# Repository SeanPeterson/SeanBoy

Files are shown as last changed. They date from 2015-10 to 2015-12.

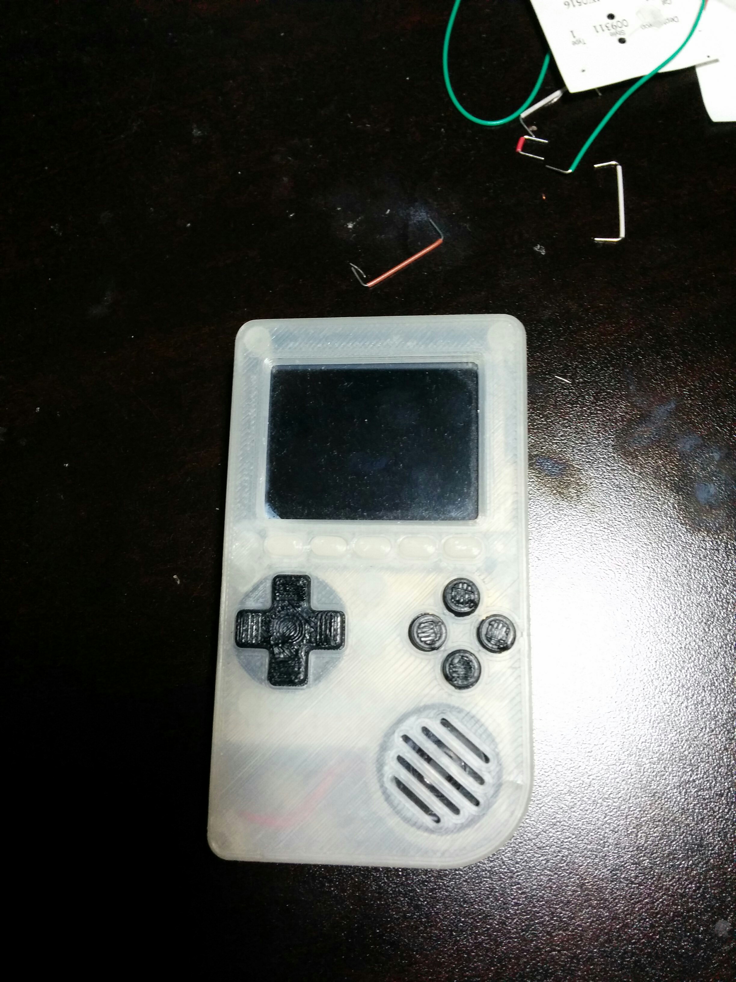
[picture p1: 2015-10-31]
Img/IMG_20151020_160937.jpg

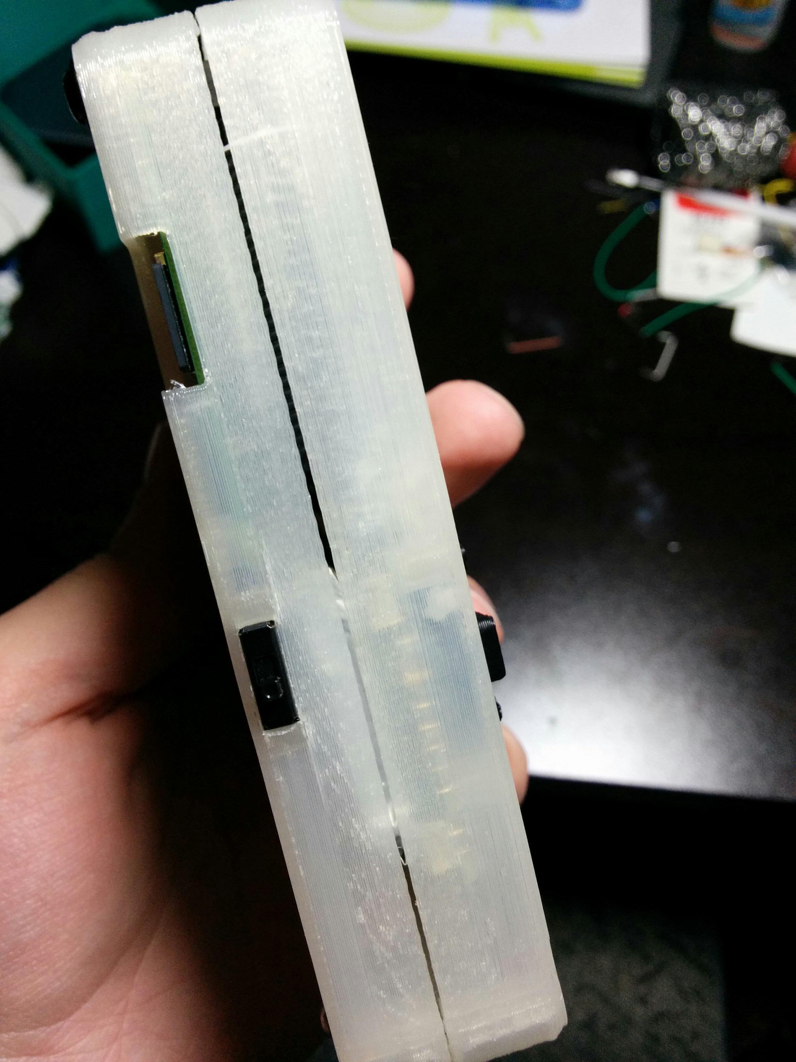
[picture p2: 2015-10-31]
Img/IMG_20151020_160956.jpg

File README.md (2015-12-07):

# CS207 Final Project
# A fork of the Pocket PiGrrl
Sean Peterson - University of Regina
*Fall 2015 *

#Video of Assembly
https://youtu.be/0lDeOTESRT8

# Overview
The goal of this project is to improve upon Adafruit’s Pocket Pigrrl design in various ways. Ultimately the plan is to roughly keep the same dimensions while also adding a Raspberry Pi 2, an audio jack, and improving durability by ensuring that everything fits snuggly. From the software standpoint the project plans on providing a method in which the save states of games can not only be backup up to a cloud service, but that will effectively sync saved games between devices that are linked to the same cloud service.

# Goals
1. The first milestone will be to build the original Pocket PiGrrl design. This will achieve a few things. Firstly, it will provide a good idea of the amount of space there is to work with. Secondly, it will help to understand the logic behind their design

2. The second milestone will be the inclusion of an audio jack. The PiGrrl currently only supports sound through a speaker which is inconvenient when there are other people in the same room as you. Doing this may require wiring a switch, to switch between the speaker and headphones.

3. The third milestone will be to use a different button design. This is because the PiGrrl uses NinjaFlex filament to print their buttons. Unfortunately this is a material not supported by the author’s 3D printer. Instead, the plan will be to take apart an original, or knock off, snes controller and use its buttons instead. This will both eliminate the noise  

4. The fourth deliverability will be to backup save states to a cloud service, and also have the saves sync between different Raspberry Pi’s that may be connected to a single account. 

5. The fifth deliverability will be to use a Raspberry Pi2 instead, while keeping the size roughly the same. This would be a welcome improvement as it would greatly improve the systems emulation capabilities. As well, this may also mean adding an improved power supply to the console. 

<h1>Build Instructions (Currently for goal 1 to goal 3)</h1>

-download CAD files from CAD folder (currently for goal 3), and print (Goal one/original design by AdaFruit found: https://www.thingiverse.com/thing:807591) <br>
-Pocket PiGrrl build instructions can be found here: https://learn.adafruit.com/pocket-pigrrl/overview <br>
(Go to goal 2 section to see how to install audio jack. <br>
-Download latest ISO image from Software folder. Install on SD card for Raspberry Pi (detailed installation instructions <br>
for different operatings systems can be found in the info file inside software directory). <br>
-Button mappings for Adafruit's PiTFT screen can be found here: https://learn.adafruit.com/pocket-pigrrl/software-1 <br>
-See goal 3 for assembly instructions https://github.com/SeanPeterson/SeanBoy/blob/master/Goal-3/goal3.pdf
# Known Issues/Planned fixes
-(FIXED - SEE GOAL 1) Currently the sound has major interference.. This problem seems to be a known issue as reported on the AdaFruit forums that is either resulting from the AdaFruit's amp, or the pi itself. <https://forums.adafruit.com/viewtopic.php?f=50&t=79200> <br>
-(FIXED IN GOAL 3) There's a gap between the top and bottom of the gameboy case. May need to extend sides and sand it down.<br>
-(FIXED IN GOAL 3) Magnet not doing a good job of keeping the case close, another screw in bottom right corner would work better. <br>

#Materials
-Raspberry Pi A+ (Exluding goal 5): <br>
-2.4 Pitft screen: https://adafruit.com/products/2455<br>
-Powerboost 1000C: https://adafruit.com/products/2465<br>
-SparkFun mono amp breakout: https://www.sparkfun.com/products/11044<br>
-Battery: https://www.adafruit.com/products/2011<br>
-Solder breadboard: http://www.amazon.ca/s/ref=nb_sb_noss_2?url=search-alias%3Daps&field-keywords=solder+breadboard<br>
-26 pin ribbon cable: https://www.adafruit.com/product/862<br>
-Tactile buttons: https://www.adafruit.com/product/1489<br>
-Mini speaker: https://www.adafruit.com/product/1890<br>
-Slide switch <br>
-Knockoff nes controller: http://www.amazon.ca/RetroLink-NES-Classic-USB-Controller/dp/B009DG2WZS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<br>
-Audio jack: http://www.canadarobotix.com/cables-wires/audio-jack-3-5-mm<br>
-6 pin switch: Scavange from old electronics<br>

# Project
Code, and diagrams can be found here: https://github.com/SeanPeterson/SeanBoy

Note: Work in progress, code/diagrams are added as worked on
This is free and unencumbered software released into the public domain. <br>

#Contact
Email: seanpeterson.997@gmail.com <br>
For questions about the project the best place to ask is on this projects Thingverse page <br>
Link coming soon ...

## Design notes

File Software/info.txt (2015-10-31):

<h1>Install info</h1>

ISO from Adafruit contains operating systems (RetroPie) complete with EmulationStation (emulators) and <br>
Adafruit's software for a ptft screen. <br>

Code and inputs for buttons on Ptft screen 

<h1>Installing image onto SD card for Raspberry PI</h1>

<h2>Windows</h2>
1) Format drive to FAT32 <br>
Note: Since windows can't see the OS partition, a 3rd party software solution is required for this. <br>
I recommend the free program MiniTool Partition Wizard: http://www.partitionwizard.com/download.html <br>

2) Install image to SD card (Again need a 3rd party software solution) <br>
-For this I recommend the free software tool Win32 Disk Manager:http://sourceforge.net/projects/win32diskimager/

<h2>Linux</h2>
-Instructions can be found here: <br>
https://www.raspberrypi.org/documentation/installation/installing-images/linux.md

<h2>Mac OS</h2>
-Instructions can be found here: <br>
https://www.raspberrypi.org/documentation/installation/installing-images/mac.md

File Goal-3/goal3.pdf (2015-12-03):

P a g e | 1

Goal 3 Outcome

1. Materials: Page 2
2. Build Instructions: Pages 2 – 9

-Pages 2 – 3 AdaFruit Tutorials

-Pages 4-6: Buttons

- Pages 7-9: Case
3. Result Pictures: Pages 10-11
4. Problems: Page 11
5. Lessons Learned: Pages 10-11

Materials

-Retrolink Nes controller: Can be found on Amazon: http://www.amazon.ca/RetroLink-NES-Classic-USB-Controller/dp/B009DG2WZS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 (http://www.amazon.ca/RetroLink-NES-Classic-USB-Controller/dp/B009DG2WZS)

-Solder breadboard

-Lenline brush to scrape the traces.

Build Instructions

1) Install power switch: https://learn.adafruit.com/pocket-pigrrl/switch
2) Install power boost 1000: https://learn.adafruit.com/pocket-pigrrl/powerboost-1000c
3) Not using the PAM8302, instead using Sparkfun Mono amp found Here: https://www.sparkfun.com/products/11044

Setup is still the exact same as AdaFruit’s: https://learn.adafruit.com/pocket-pigrrl/pam8302

5V from powerboost to PWR + on amp

GND from powerboost to PWR – on amp

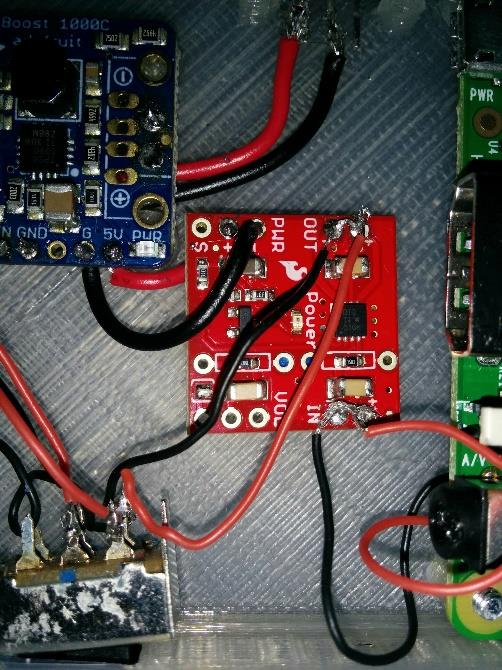
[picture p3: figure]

4) Pi audio: https://learn.adafruit.com/pocket-pigrrl/pi-audio
5) Speaker: https://learn.adafruit.com/pocket-pigrrl/speaker
6) Screen: https://learn.adafruit.com/pocket-pigrrl/2-dot-4-pitft

Buttons taken from a retrolink nes controller:

7) Pi Cable: https://learn.adafruit.com/pocket-pigrrl/pi-cable
8) Mount display: https://learn.adafruit.com/pocket-pigrrl/mount-display
9) Installing buttons:

-Cut out breadboard that fits snuggly into case aprox(63mm wide, 53mm long)

Take Apart a RetroLink Nes controller and remove PCB board.

Make cuts so that they fit on proto board and line up with the button cut outs on the case

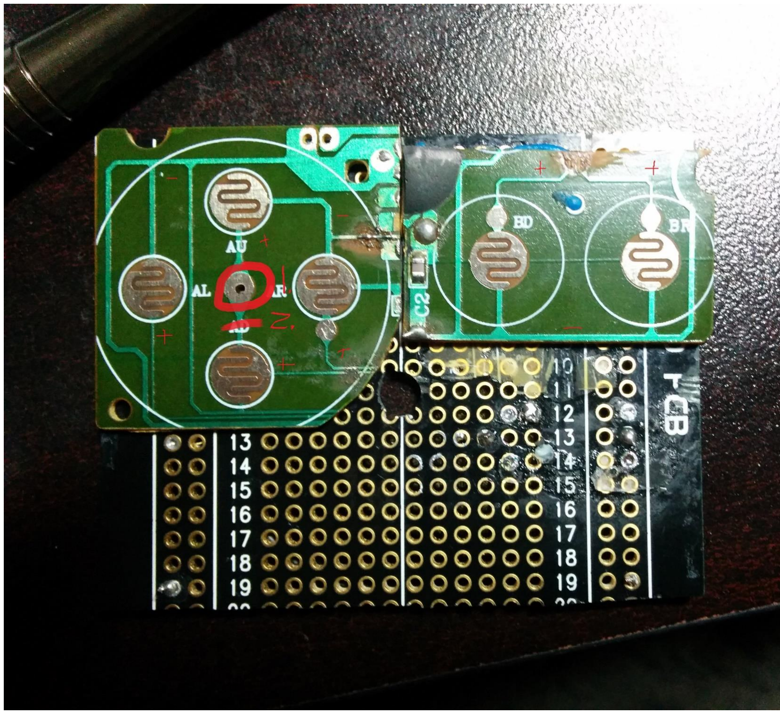
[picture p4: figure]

1. Needed drill press to make a hole here so that I could get the up wire to the button
2. Trace cut

+ are the traces that I wired the buttons to

- Are the ground traces.

Make sure that each button has a ground (can be shared), and a positive (where the button will be wired). Expose the trace by scraping it with a Lenline brush, and tin the location you desire to prepare for the solder. This may require using a drill press as seen in picture above to make a hole in a specific location. As well, you may need to perform trace cuts.

-Also ensure that the wires are not underneath the elastomer gaskets as that will effect the feel and functionality. Instead make sure buttons are wired at enough of a distance away from the elastomer gaskets to allow for some mistakes to be made (if a trace falls off).

-Now solder the button wires from the screen to the breadboard. Buttons can of course go to any location on your breadboard that is convenient but here is my set up in the picture below.

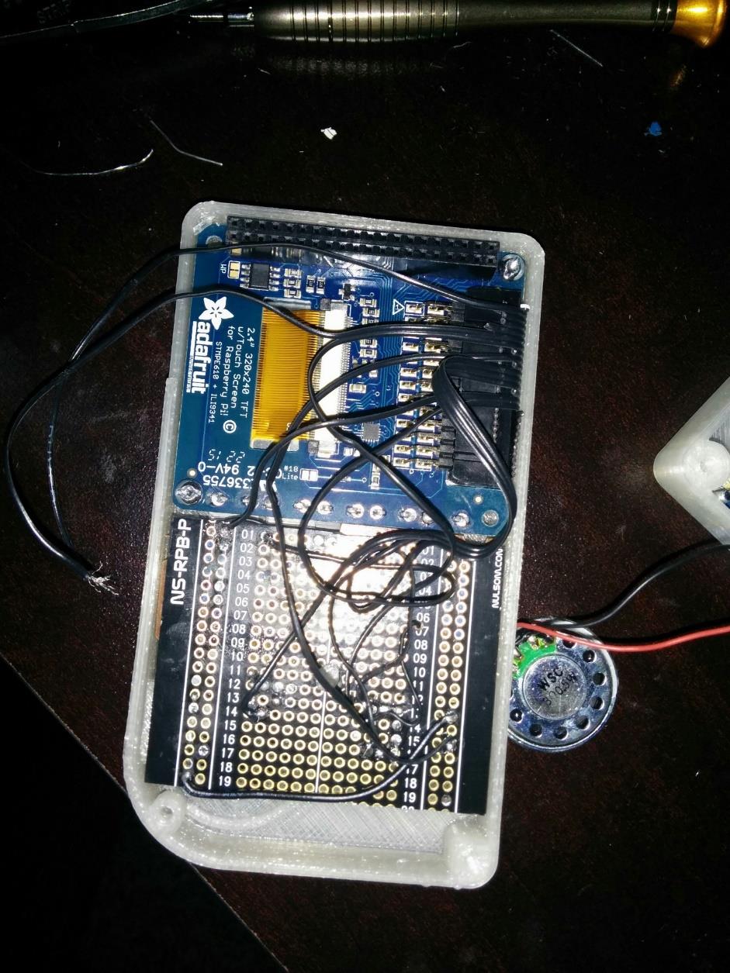
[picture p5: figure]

(Wired the buttons to the back of the breadboard, then from the breadboard to the buttons)

The wire numbers are the same as AdaFruit’s tutorial found here: https://learn.adafruit.com/pocket-pigrrl/buttons

Note rows are split in half (ex say row 16 can have wires on both sides)

#9 Ground → Goes to ground of breadboard (I’ve connected both grounds together as seen above)

#7 Left → row 16 (Dpad side)

#11 Right → Row 15

#12 Up → Row 14

#13 Down → Row 13

#15 A → Positive Row (on the buttons side)

#16 B → Row 1

-Now wire from the BreadBoard locations to the correct buttons.

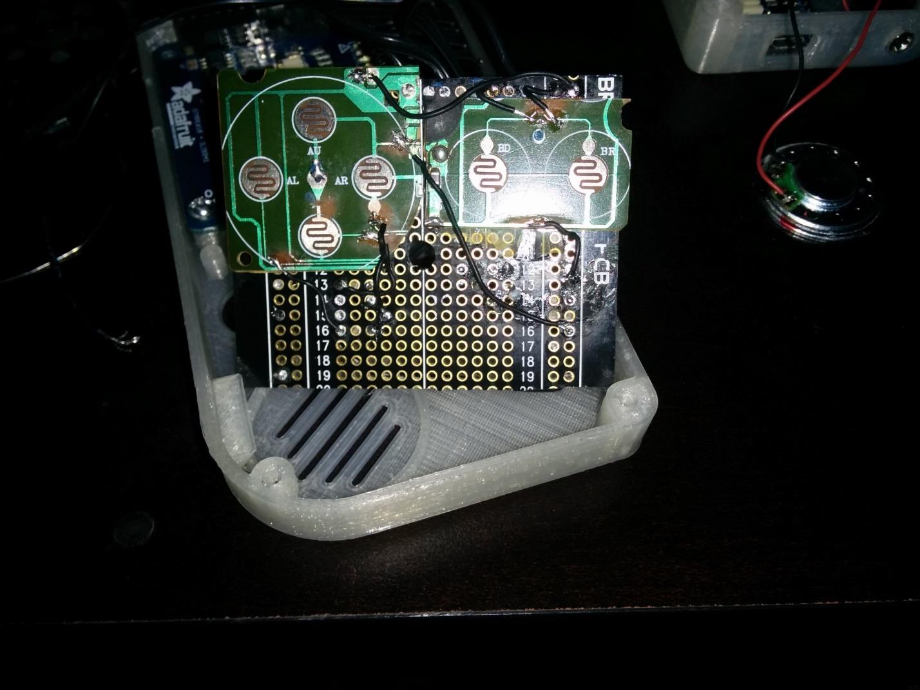
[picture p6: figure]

-Place the buttons in the correct slots. Line up the elastomer gaskets on top of the buttons (a small amount of sticky tack may help but too much will hinder it).

-Line the breadboard up with the screw hole standoff (should also be resting on the four corner standoffs) and screw into place with a SIZE screw.

-Assemble the case, same as Adafruit instructions excep that there is a screw in bottom right corner instead of a magnet.

https://learn.adafruit.com/pocket-pigrrl/assembly

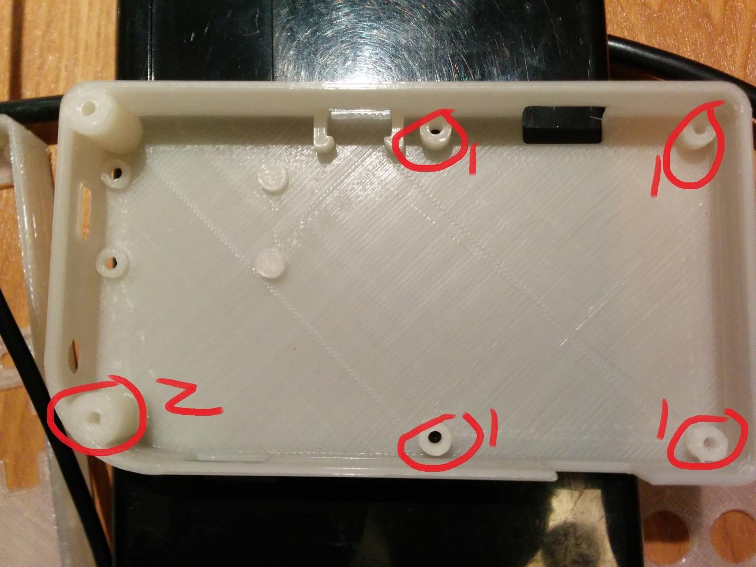
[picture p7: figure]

(Modifications made to the bottom of the case)

1: Raised screw standoffs for Raspberry Pi by 2mm

2: Added screw hole for bottom left side of case (will screw into the top case to replace the magnet in Adafruit’s design).

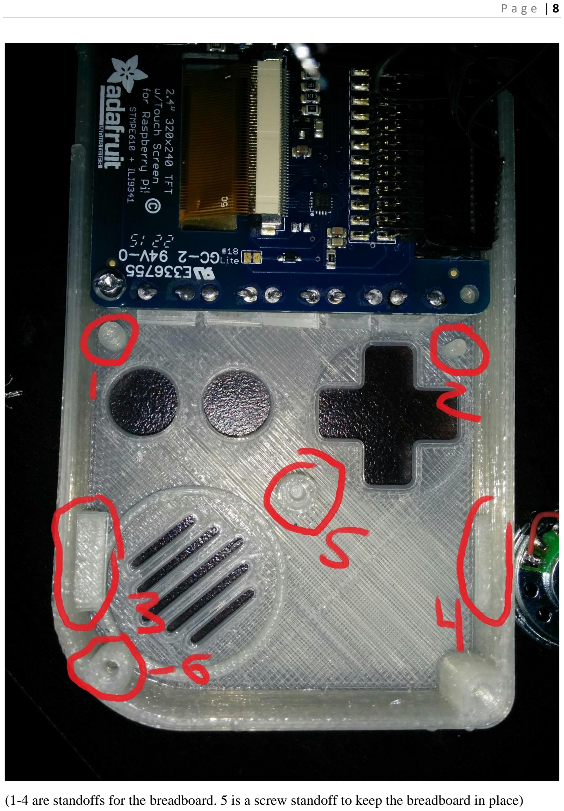
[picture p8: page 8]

(1-4 are standoffs for the breadboard. 5 is a screw standoff to keep the breadboard in place)

1-4 are to prevent the breadboard from tilting in any direction when a buttons are pressed. 5 is to prevent the bread board from moving horizontally out of place. (The case will be packed enough that the breadboard will not be able to move horizontally out of place.

6. Screw hole that replaces the magnet that is in Adafruit’s design

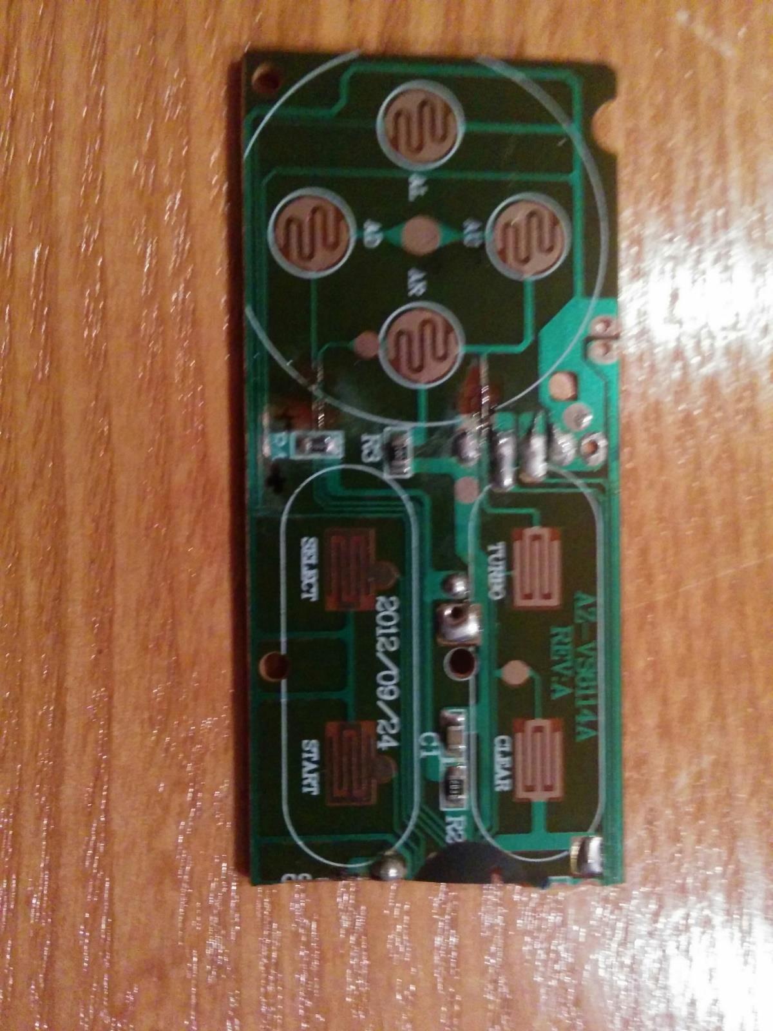
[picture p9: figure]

(DPAD PCB before the cut)

Result Pictures

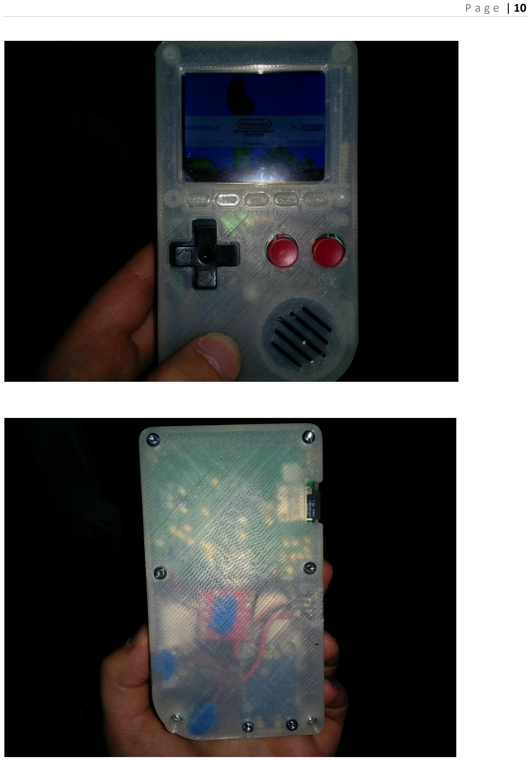
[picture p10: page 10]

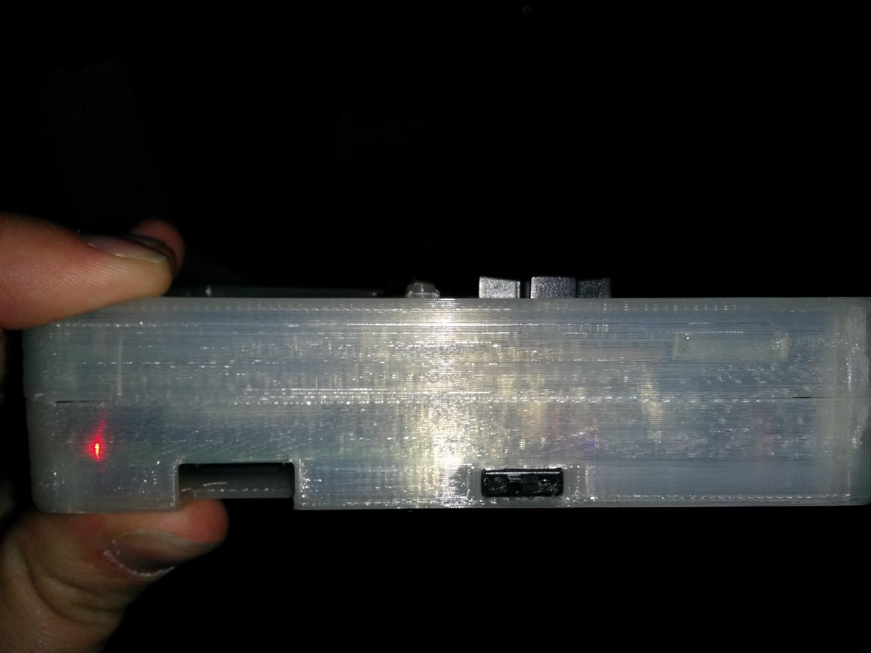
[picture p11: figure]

Problems

Problem: The buttons could still use some improvement in resistance to presses.

Solution: Minor tweaking with space (lower the standoffs a bit more)

Problem: GPIO pins on pi could fit a bit better into the screen

Solution: Tweak the height of the Raspberry Pi’s standoffs (probably just a mm or two)

Lessons Learned

1. This goal ended up being a lot more challenging than initially expected. A general principle I’ve learned is that when scavenging buttons from a controller it is a good idea to try and implement the same (or similar) design as was being used in the controller you took the buttons from.

2. Don’t have any wires soldered below the elastomer gaskets as they will get in the way of button presses and make the buttons unreliable and uncomfortable.
3. Leave lots of room to solder the wires to the traces as pulling a wire too hard will often rip a piece of the trace off of the PCB.
4. Spacing is extremely important to the feel and functionality of the buttons (resulting in a lot of prototyping in the CAD design).

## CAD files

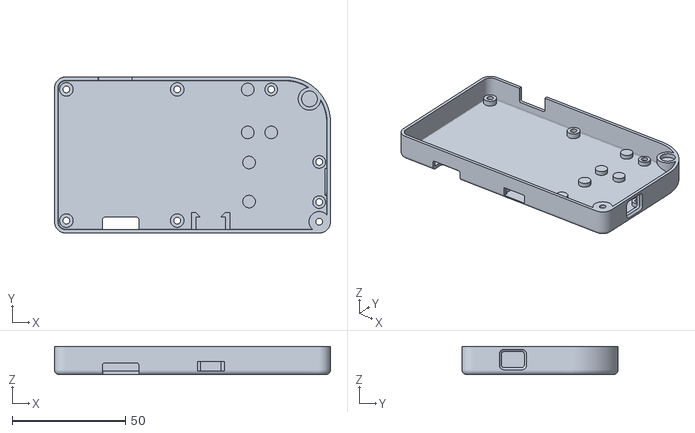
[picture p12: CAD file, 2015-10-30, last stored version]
CAD/pgp-4-bot.stl
122.0 x 69.0 x 12.4

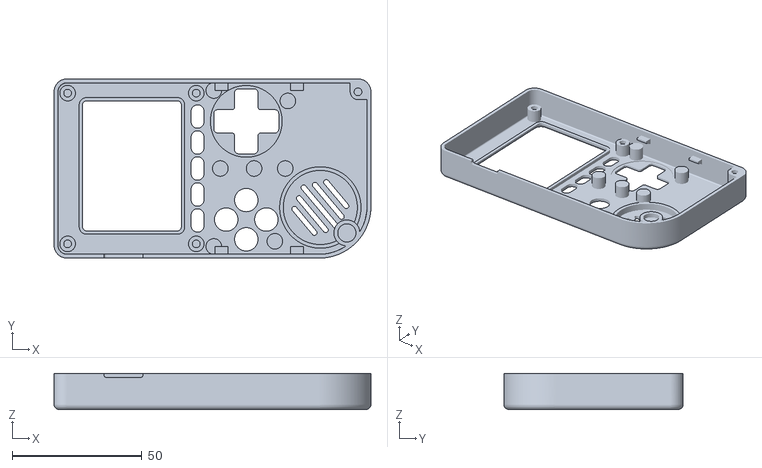
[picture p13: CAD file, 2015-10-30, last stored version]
CAD/pgp-4-top.stl
122.0 x 69.0 x 13.9

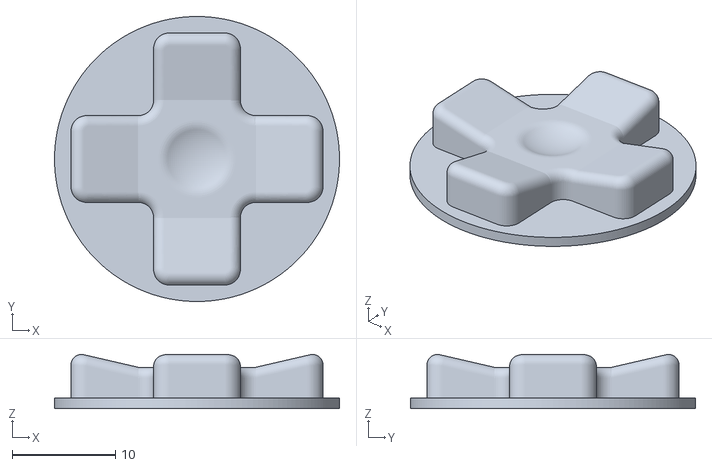
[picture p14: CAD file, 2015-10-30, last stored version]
CAD/dpad.stl
27.6 x 27.6 x 5.24

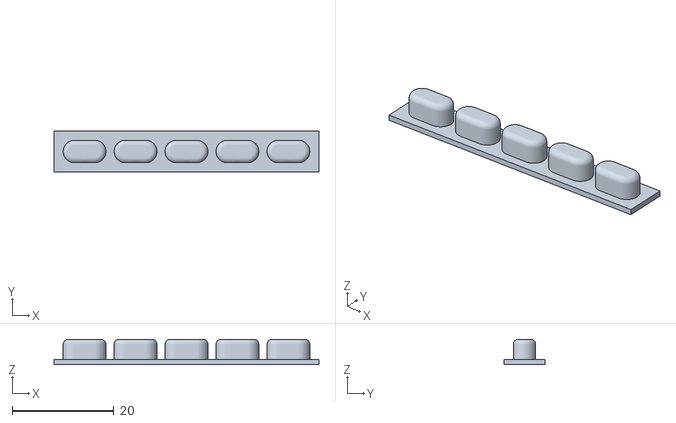
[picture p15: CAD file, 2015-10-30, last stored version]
CAD/PiTFT-Buttons.stl
52.0 x 8.00 x 5.00

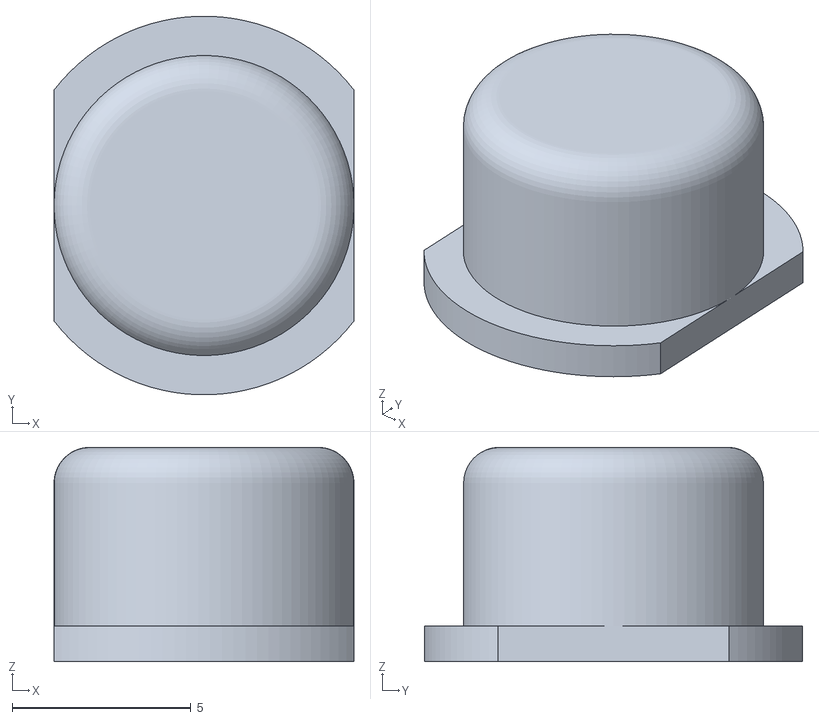
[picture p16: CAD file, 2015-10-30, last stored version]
CAD/hard-btn.stl
8.40 x 10.6 x 6.00

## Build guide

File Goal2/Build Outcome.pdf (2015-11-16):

P a g e | 1

Goal 2 Build Outcome

1. Additional parts needed:
-3 Prong switch:
http://www.canadarobotix.com/mechanical-switches/1480-dpdt-slide-switch-3a-125v (or just scavenged from somewhere)
-Headphone jack:
http://www.canadarobotix.com/cables-wires/audio-jack-3-5-mm
2. Build Pictures: Pages 2-6
-Page2: Diagram
-Page3: Build picture.
3. Problems encountered/Solutions: Pages 6-7 -Gap between front and back ends
-Does not close that well
-Audio issues
4. Lessons Learned: Page 7
-Drill press required
-function buttons without NinjaFlex plastic filament

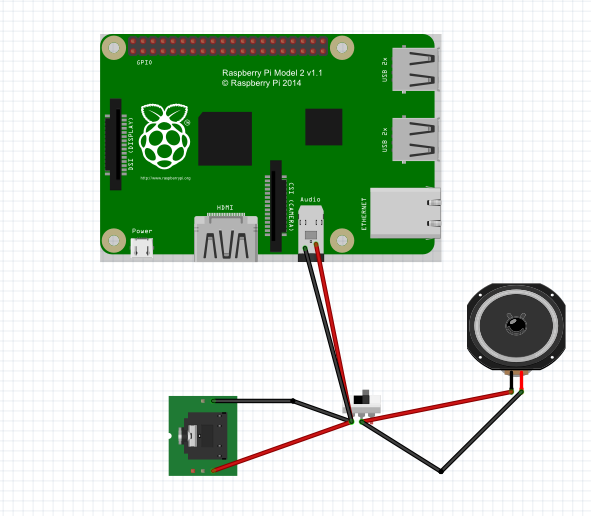
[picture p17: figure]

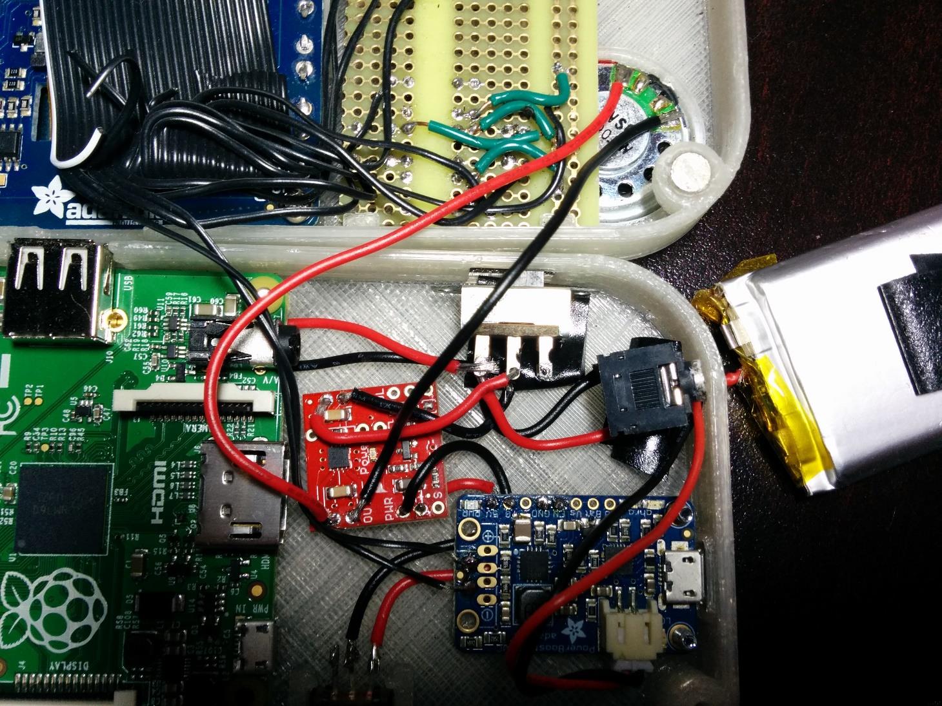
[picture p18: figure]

Potential Improvement

-May use an audio jack breakout in future revision (although a switch is easier to get a hold of).

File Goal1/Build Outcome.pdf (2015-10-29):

P a g e | 1

Goal 1 Build Outcome

1. Adafruit’s instructions/code for the Pocket Pigrrl build can be found here: https://learn.adafruit.com/pocket-pigrrl/overview
-Was made with PLA (clear) and ABS (black) plastics
2. Build Pictures: Pages 2-6
-Page2: Build of Pocket PiGrrl
-Page3,4: Gap between front and back ends. -Page5,6: Inside of Pocket PiGrrl
3. Problems encountered/Solutions: Pages 6-7 -Gap between front and back ends
-Does not close that well
-Audio issues
4. Lessons Learned: Page 7
-Drill press required
-function buttons without NinjaFlex plastic filament

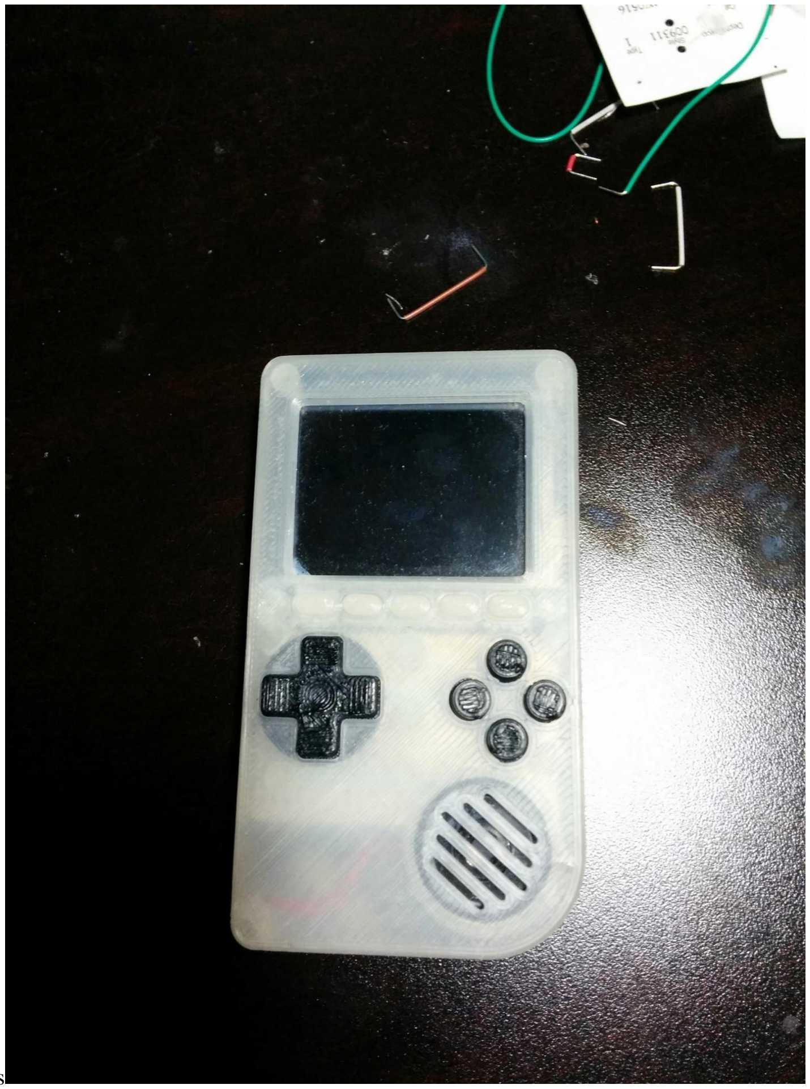
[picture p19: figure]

s

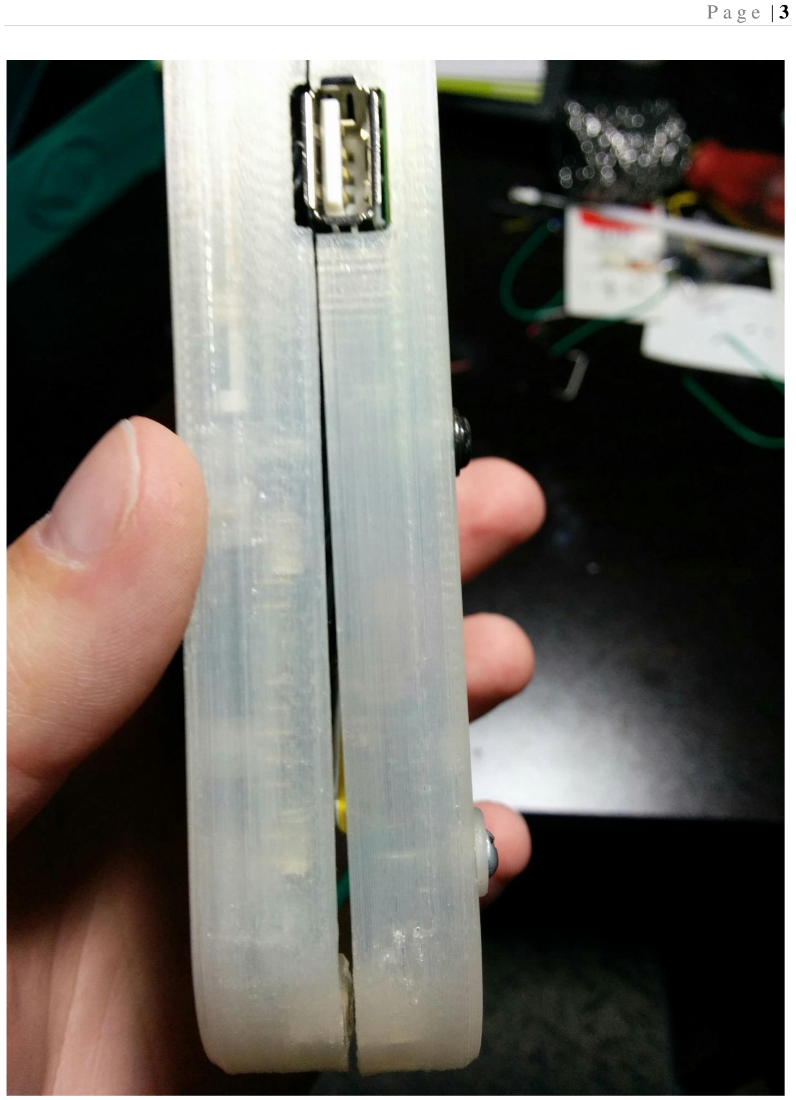
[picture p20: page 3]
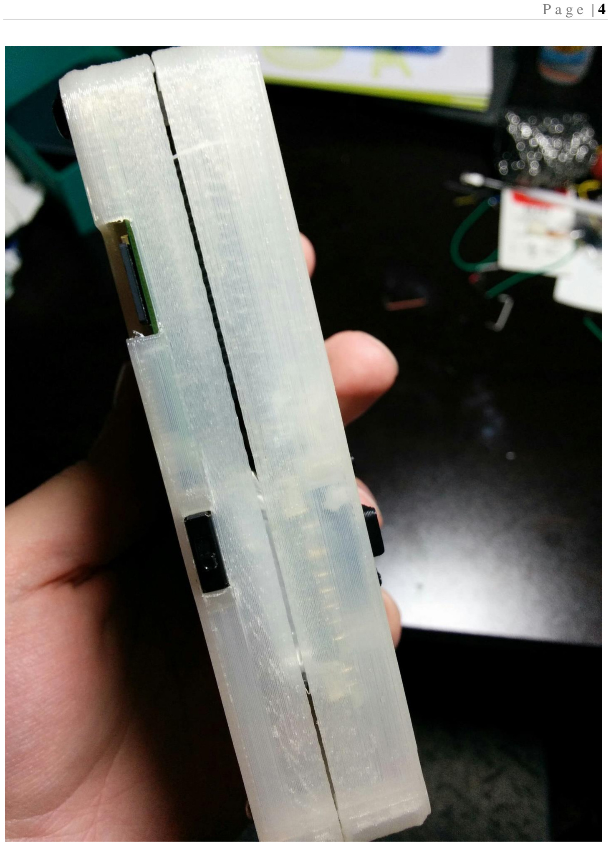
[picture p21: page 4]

From these last two pictures you can see the fairly large gap between the two pieces. Firstly everything is packed pretty tightly causing resistance when closing. Also I will most likely use stranded wire in the future for more flexibility. Lastly, the magnet as seen below does not help in closing the gap.

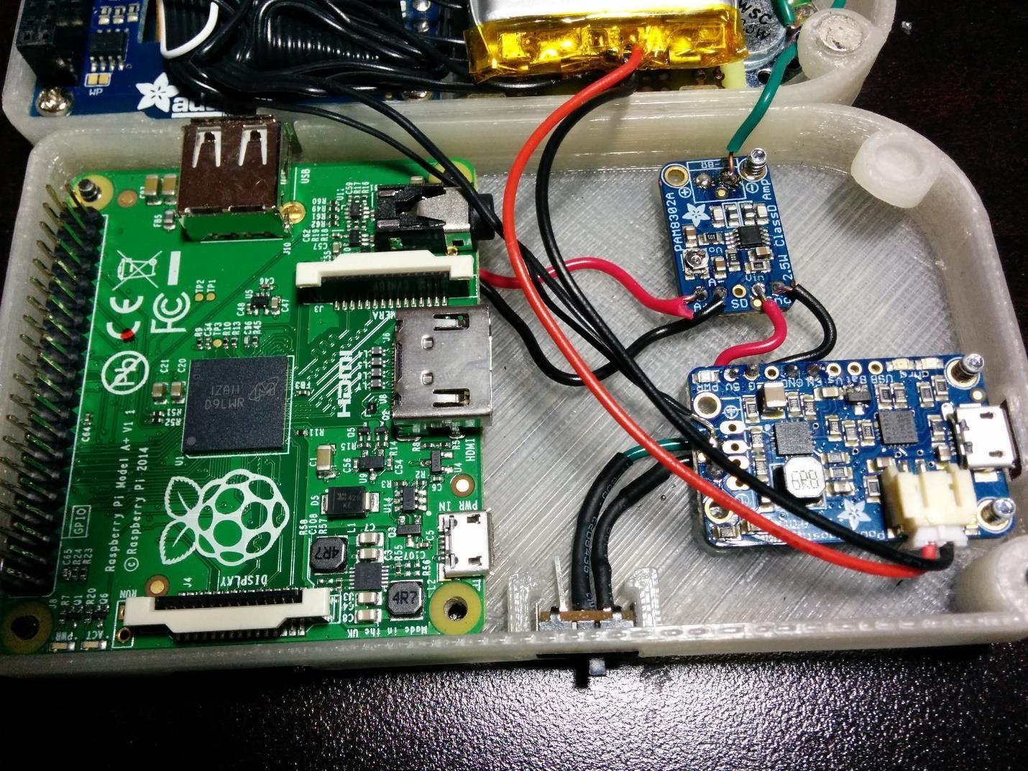
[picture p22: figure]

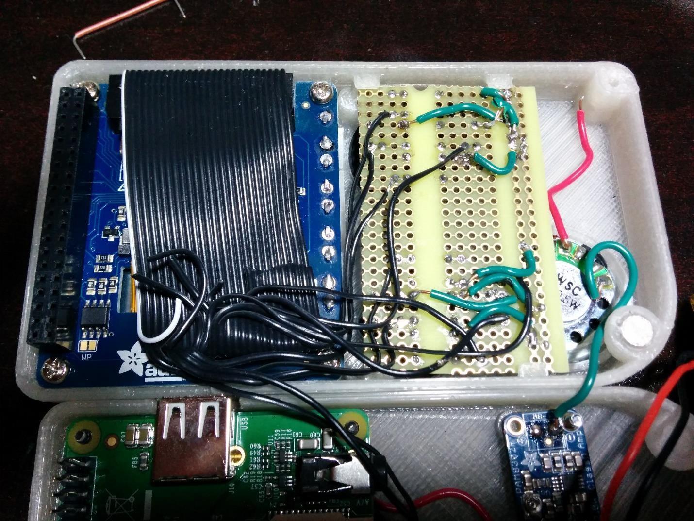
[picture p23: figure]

The speaker is not attached here because audio is has major issues coming out of the pi, and AdaFruit’s Amp is not helping to smooth it out.

Problems

Problem: Gap between front and back sides.

Proposed Solution(Not Yet Attempted): This may be a limitation with my 3D Printer and so a complete CAD solution may not be possible. Instead I will Increase the height of the sides and sand them down a bit to make them level.

Problem: Magnet is not strong enough to keep it securely closed.

Proposed Solution:
-Increasing the sides slightly will help with providing more room for the components inside. -Stranded wires vs solid will be more flexible and provide less resistance when closing. -In the CAD design, replace the magnet with another screw.

Problem: The audio has major interference. This appears to be a well reported issue with the Pi (Not yet sure about the Pi2), and plugging in headphones directly to the Pi confirms this. Adafruit’s amp dies not improve this.

Proposed Solution: Plan on trying another amp. Currently no concrete solution.

Lessons Learned

1. A drill press is required for this project. Not using one, as I’ve learned’ ends in many of the screw standoffs breaking. Also makes it difficult to take screws out thus reducing the cases durability.
2. Because I’m not using Ninja Flex for the buttons, the top functional buttons needed to be broken apart from each other to work. This does work but it is possible for the buttons to rarely fall out which can be extremely frustrating to get them back in without taking apart the Gameboy.
3. AdaFruit provides an outdated ISO image for RetroPie. Using a fresh image of RetroPie, then installing AdaFruit’s Pftft screen libraries caused major problems with the button inputs. Best solution is to update the image that they provide.

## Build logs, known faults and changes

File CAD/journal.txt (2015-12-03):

bottom 1.0

raise outside by 2mm
raist pi standoffss 2mm
add screw holes for switch 4mm

top 2.0
increase button by 1mm (12mm total)
lowered button breadbold screw by 1mm (make even with breadboard holders)
Reduced thickness of breadboard holders (1mm)

top4.0
-removed top two breadboard standoffs
-added stands (lowered 1.5mm from original standoffs) height=7.3mm
lower everything by 1mm (including above so now 6.3mm)

top (failed)
lower buttons another mm
wider standoffs
add things for breadboard 2mm from others

bottom v3
raise everything 1mm
attempt to get left corner screw lien
increased sd card 2mm

top5.0
lower buttons another mm
wider standoffs

bottom v4 (failed)
move screw hole bootms right 1mm back
sink holes  .5mm

top 6
expand bottom left bb by 3mm

bottom v4
move screw hole bootms right 1mm back

top7
expand to back bb holders

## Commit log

2015-10-30 Software
    software (iso and button mappings) required to run a Pocket PiGrrl
2015-10-30 create CAD folder
2015-10-30 added stl files for Pocket PiGrrl
    These are the original CAD designs for AdaFruit's Pocket PiGrrl
    [PiTFT-Buttons.stl, dpad.stl, hard-btn.stl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]
2015-10-30 Added Original CAD reference
2015-10-30 added AdaFruit CAD reference
2015-10-31 added iso instructions
    How to install iso image to SD card for Raspberry Pi for Windows, Linux, Mac
2015-10-31 Added goal 1 images
    Pocket PiGrrl Build, outside and inside of case
2015-11-16 added goal 2, and materials section
2015-12-03 Added CAD files for goal 3
    [PiTFT-Buttons.stl, dpad.stl, hard-btn.stl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]
2015-12-07 added materials
2015-12-07 fixed mistake in materials
2016-08-28 photo of audio switch
